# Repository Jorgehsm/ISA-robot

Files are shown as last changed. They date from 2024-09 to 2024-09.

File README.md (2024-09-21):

# ISA robot
Carro robô baseado em esp32 controlado por controle bluetooth.

O projeto utiliza Bluepad32 na comunicação entre o controle e o esp32. Para mais informações acesse: <https://bluepad32.readthedocs.io/en/latest/plat_arduino/>

Desenvolvido utilizando Platform.io.

Breakout board para conexão do esp32 com os diversos sensores e componentes utilizados desenvolvida utilizando KiCad.

imagem

Modelagem do chassi para fabricação em impressão 3D desenvolvida utilizando SolidWorks.

Sem título

Projeto pessoal em desenvolvimento.

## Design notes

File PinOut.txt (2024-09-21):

IR FRENTE - 2
ULTRASSOM - 	TRIG 19
		ECHO 23
ACCEL -	SDA 21
	SCL 22

IR ESQ - 34
IR DIR - 35
BUZZER - 13
BOTAO - 4
LED
LED

MOTORES
ENA 14
IN1 27
IN2 26
IN3 25
IN4 33
ENB 32

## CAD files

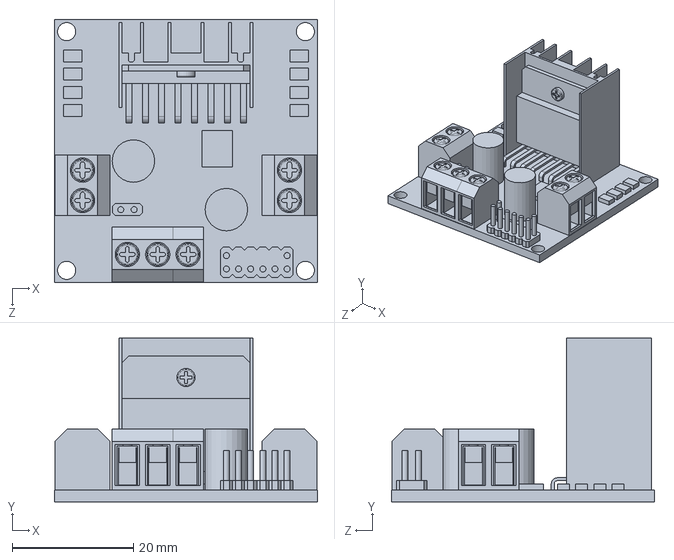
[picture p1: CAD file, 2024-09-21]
CAD/L298N.SLDPRT
43.3 x 27.0 x 43.3 mm

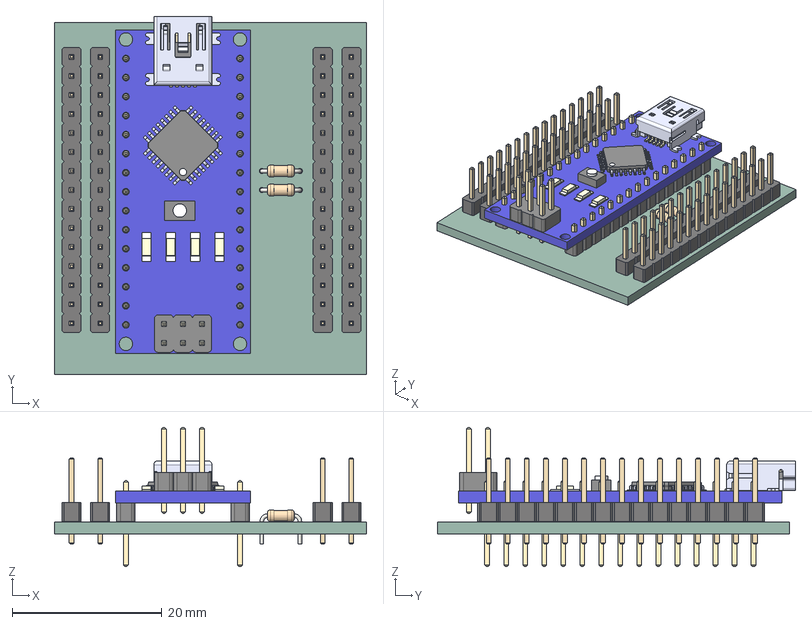
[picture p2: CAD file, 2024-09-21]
pcb_robo_isa_esp/pcb_robo_isa.step
41.7 x 47.8 x 18.6 mm
PinHeader_1x15_P254mm_Vertical x 4
ARDUINO NANO 3.0
R_Axial_DIN0204_L36mm_D16mm_P508mm_Horizontal x 2
_autosave-pcb_robo_isa_PCB

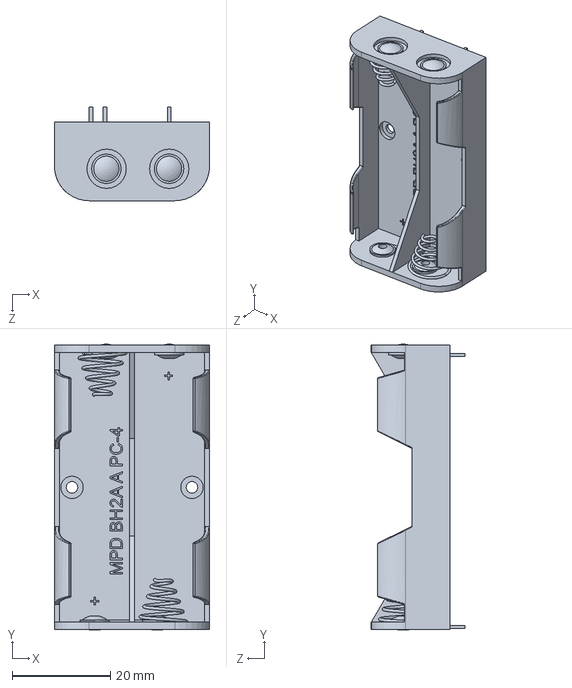
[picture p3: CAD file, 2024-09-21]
CAD/AABattery Holder.SLDPRT
31.5 x 58.1 x 19.0 mm

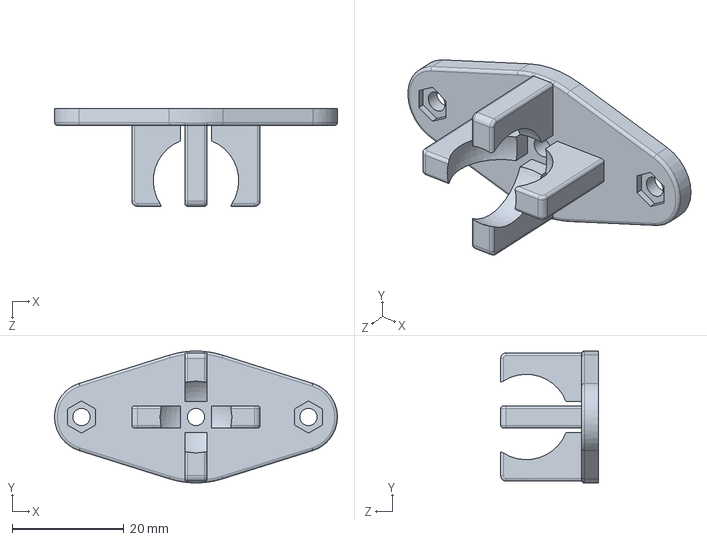
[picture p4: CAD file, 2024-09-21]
CAD/roda_boba.SLDPRT
50.7 x 23.6 x 17.5 mm

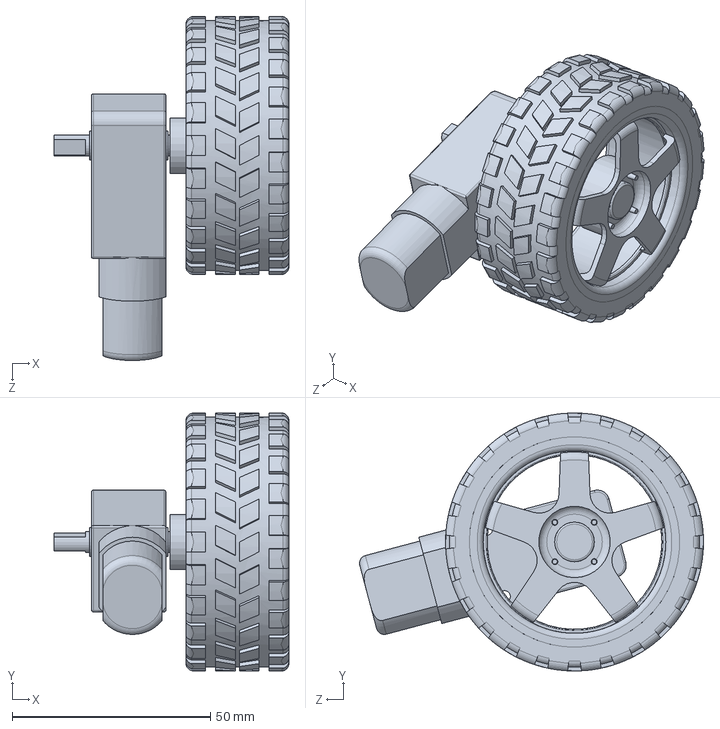
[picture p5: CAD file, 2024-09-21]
CAD/dc_motor_and_wheel.SLDPRT
59.2 x 65.0 x 86.7 mm

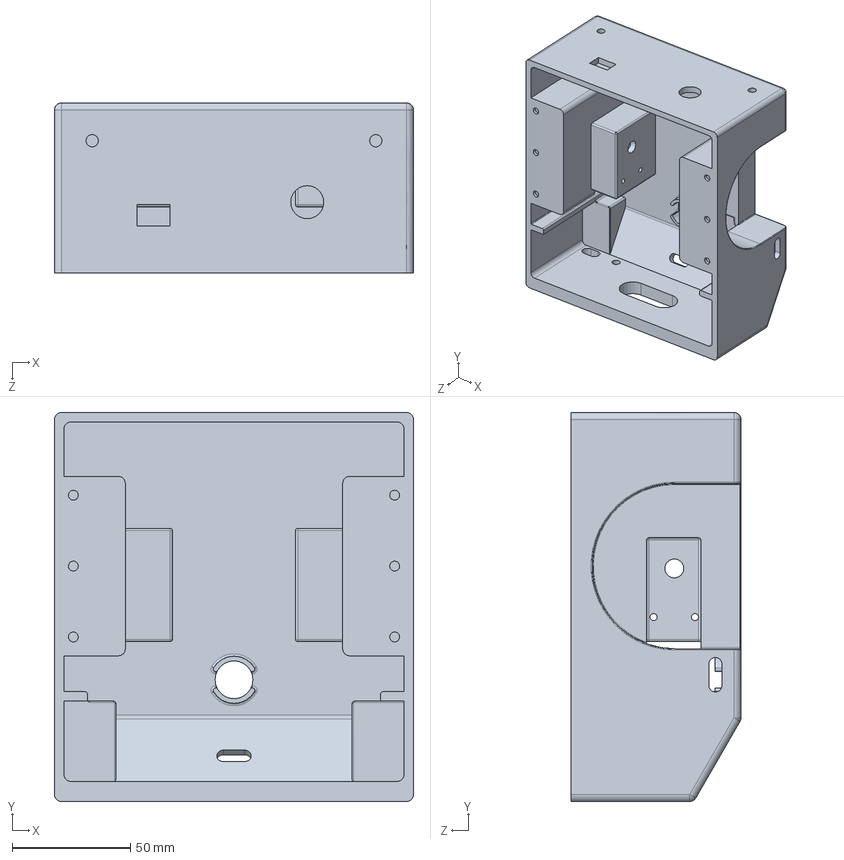
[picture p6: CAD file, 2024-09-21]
CAD/chassi.SLDPRT
152.0 x 164.6 x 72.0 mm

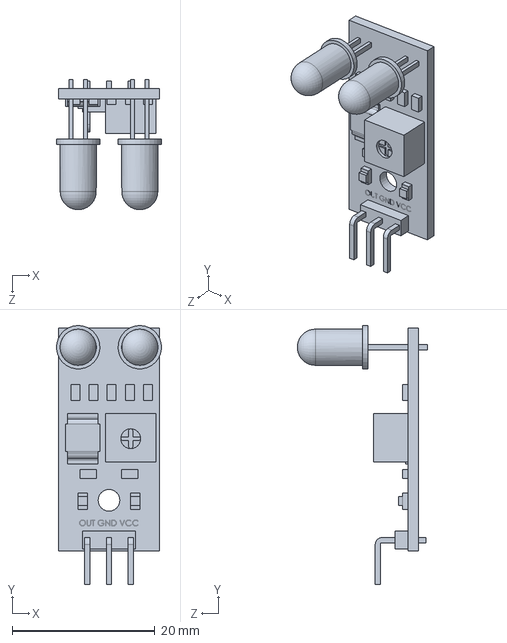
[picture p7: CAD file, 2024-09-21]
CAD/IR Sensor (FC51).SLDPRT
14.7 x 36.3 x 18.3 mm

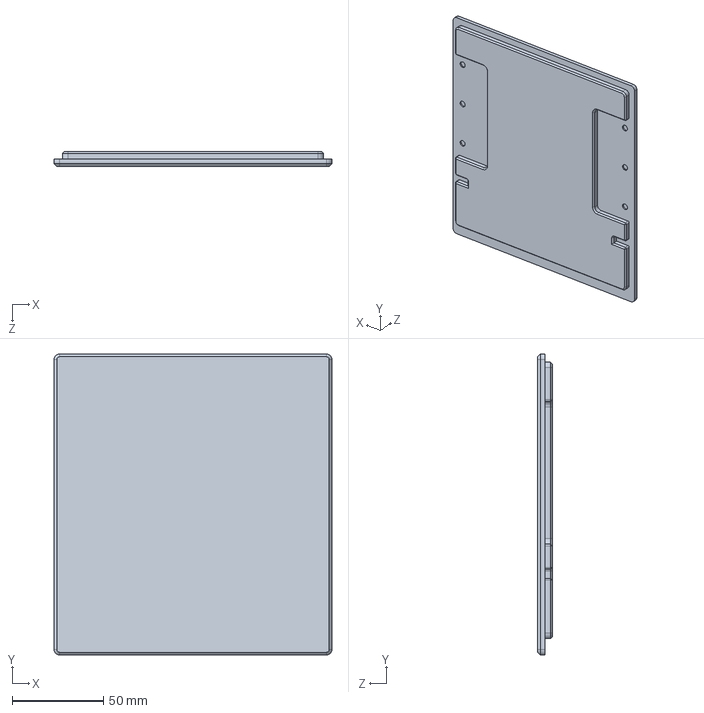
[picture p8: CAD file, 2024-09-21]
CAD/tampa.SLDPRT
152.0 x 164.6 x 8.00 mm

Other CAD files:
CAD/pcb_robo_isa.SLDPRT
CAD/chassi_rodamaior.SLDPRT

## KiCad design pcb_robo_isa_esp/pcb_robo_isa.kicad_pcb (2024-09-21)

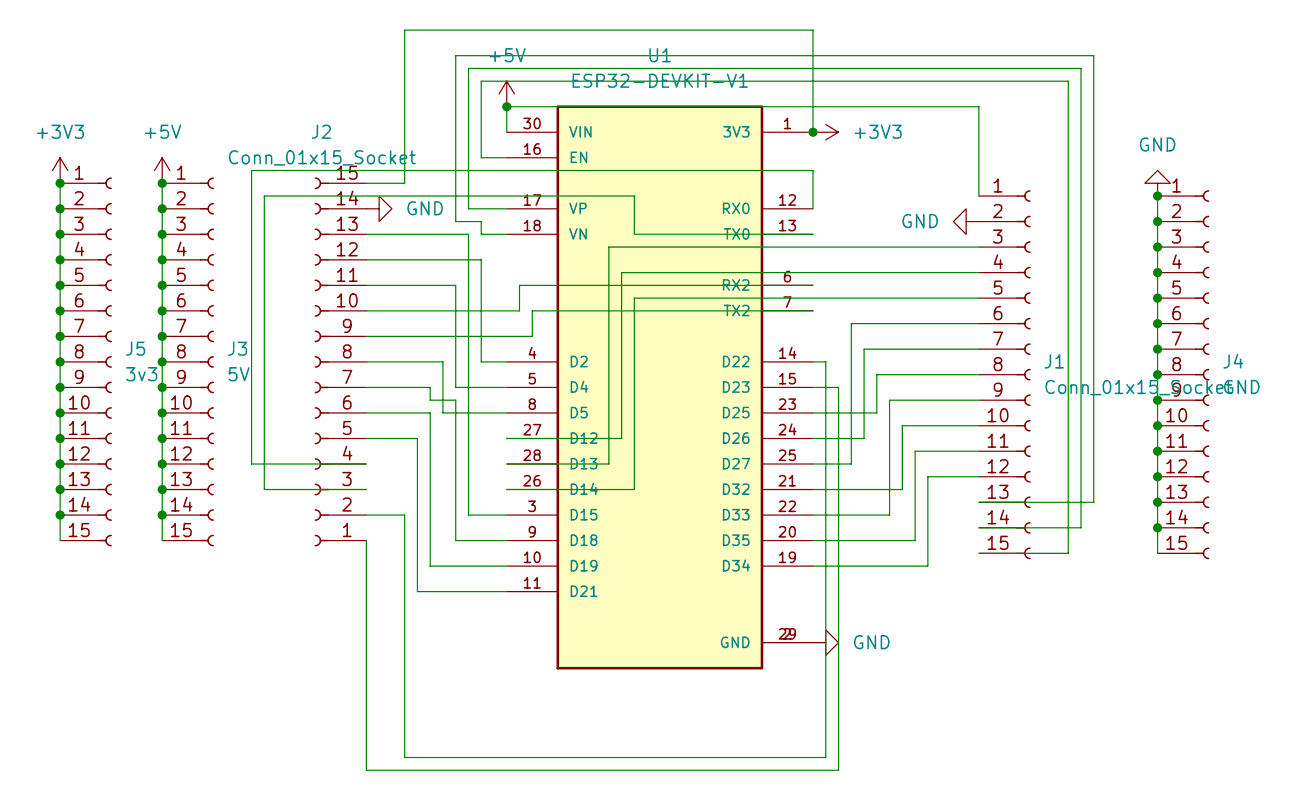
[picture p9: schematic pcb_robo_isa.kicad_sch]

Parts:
J1, J2: Conn_01x15_Socket; PinHeader_1x15_P2.54mm_Vertical
J3: 5V; PinHeader_1x15_P2.54mm_Vertical
J4: GND; PinHeader_1x15_P2.54mm_Vertical
J5: 3v3; PinHeader_1x15_P2.54mm_Vertical
U1: ESP32-DEVKIT-V1; MODULE_ESP32_DEVKIT_V1; PARTREV N/A

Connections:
+3V3: J2.15, J5.1, J5.2, J5.3, J5.4, J5.5, J5.6, J5.7, J5.8, J5.9, J5.10, J5.11, J5.12, J5.13, J5.14, J5.15, U1.1 (3V3)
+5V: J1.1, J3.1, J3.2, J3.3, J3.4, J3.5, J3.6, J3.7, J3.8, J3.9, J3.10, J3.11, J3.12, J3.13, J3.14, J3.15, U1.30 (VIN)
GND: J1.2, J2.14, J4.1, J4.2, J4.3, J4.4, J4.5, J4.6, J4.7, J4.8, J4.9, J4.10, J4.11, J4.12, J4.13, J4.14, J4.15, U1.2 (GND), U1.29 (GND)
unnamed: J1.3, U1.28 (D13)
unnamed: J1.4, U1.27 (D12)
unnamed: J1.5, U1.26 (D14)
unnamed: J1.6, U1.25 (D27)
unnamed: J1.7, U1.24 (D26)
unnamed: J1.8, U1.23 (D25)
unnamed: J1.9, U1.22 (D33)
unnamed: J1.10, U1.21 (D32)
unnamed: J1.11, U1.20 (D35)
unnamed: J1.12, U1.19 (D34)
unnamed: J1.13, U1.18 (VN)
unnamed: J1.14, U1.17 (VP)
unnamed: J1.15, U1.16 (EN)
unnamed: J2.1, U1.15 (D23)
unnamed: J2.2, U1.14 (D22)
unnamed: J2.3, U1.13 (TX0)
unnamed: J2.4, U1.12 (RX0)
unnamed: J2.5, U1.11 (D21)
unnamed: J2.6, U1.10 (D19)
unnamed: J2.7, U1.9 (D18)
unnamed: J2.8, U1.8 (D5)
unnamed: J2.9, U1.7 (TX2)
unnamed: J2.10, U1.6 (RX2)
unnamed: J2.11, U1.5 (D4)
unnamed: J2.12, U1.4 (D2)
unnamed: J2.13, U1.3 (D15)

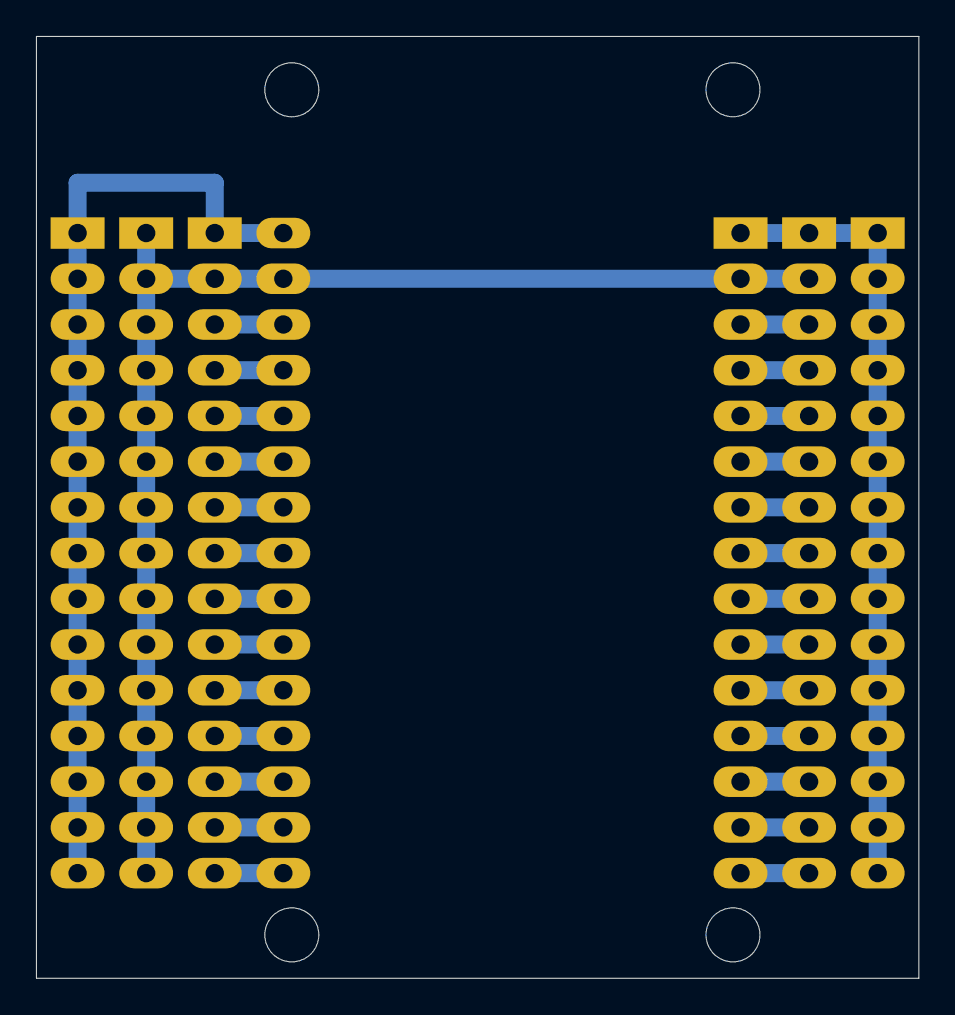
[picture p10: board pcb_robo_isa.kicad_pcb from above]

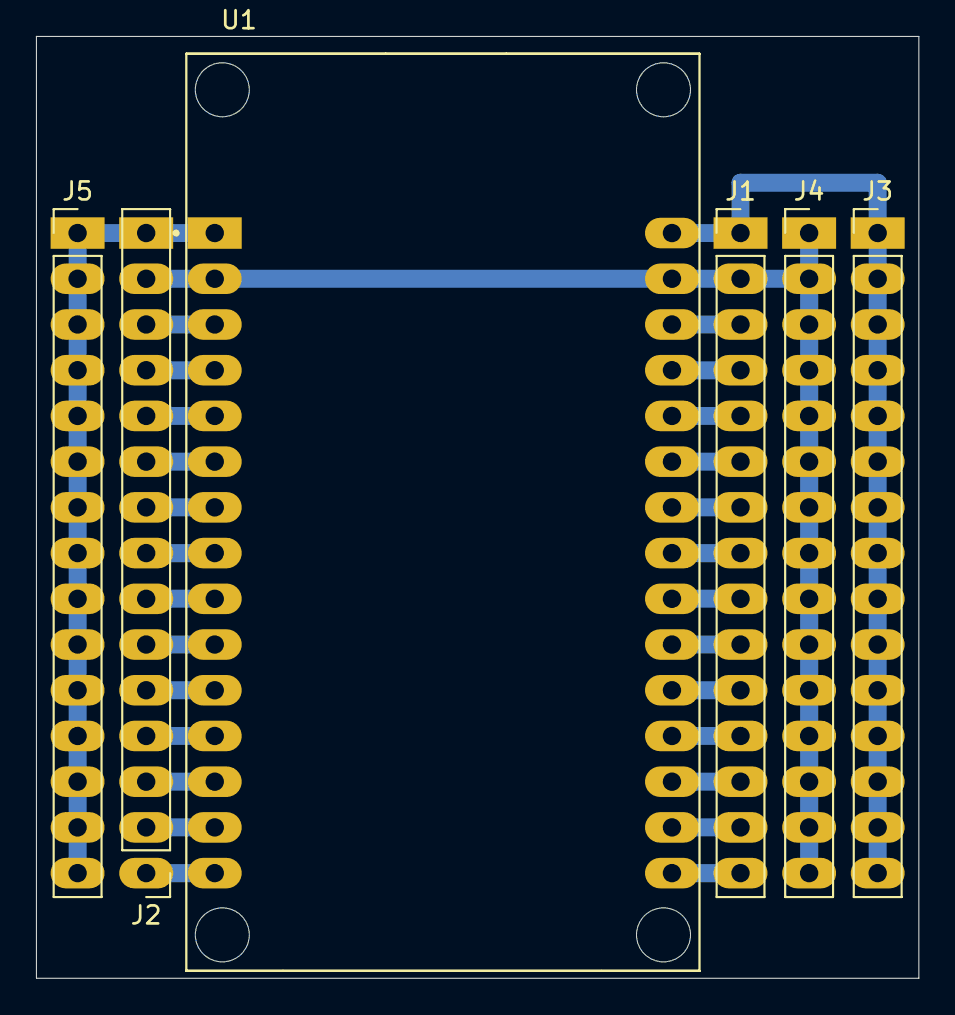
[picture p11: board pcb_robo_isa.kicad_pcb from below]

Board: 2 copper layers, 49.0 x 52.3 mm, 6 parts (6 on the bottom side), 29 nets.

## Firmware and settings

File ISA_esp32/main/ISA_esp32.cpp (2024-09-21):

#include "sdkconfig.h"
#include <Arduino.h>
#include <Bluepad32.h>

int vel = 100, modo = 0;
float turn = 1, Kp = 10, Ki = 1, err = 0, err_ant = 0, err_int = 0;
bool once = 0;
char command = 'A';
unsigned long int tempo = millis();

//*************************************************************************

//ultrassom
#define trigger 19
#define echo 23

float ultrassonico() {
  digitalWrite(trigger, HIGH);
  delayMicroseconds(10);
  digitalWrite(trigger, LOW);
  long tempo = pulseIn(echo, HIGH);
  float distancia = tempo * 0.01715;
  return distancia;
}

//*************************************************************************

//IR direita
#define IRD 34

//IR esquerda
#define IRE 35

//IR anti-queda
#define IRB 2

//************************************************************************

//motor A
#define MA1 27
#define MA2 26
//motor B
#define MB1 25
#define MB2 33

//PWM
#define ENA 14
#define ENB 32

#define M 4

int gas = 0;

//*************************************************************************

#define SPEAKER 13

void MOTOR(int vel, float turn) {
  if (vel > 0 && digitalRead(IRB) == LOW) {
    vel = 255*vel/1020;
    if (turn < 0) {
      digitalWrite(MA1, LOW);
      digitalWrite(MA2, HIGH);
      digitalWrite(MB1, LOW);
      digitalWrite(MB2, HIGH);
      analogWrite(ENA, vel * (turn + 512)/512);
      analogWrite(ENB, vel);
    }

    else if (turn > 0) {
      digitalWrite(MA1, LOW);
      digitalWrite(MA2, HIGH);
      digitalWrite(MB1, LOW);
      digitalWrite(MB2, HIGH);
      analogWrite(ENA, vel);
      analogWrite(ENB, vel * (turn - 508)/-508);
    }

    else if (turn == 0) {
      digitalWrite(MA1, LOW);
      digitalWrite(MA2, HIGH);
      digitalWrite(MB1, LOW);
      digitalWrite(MB2, HIGH);
      analogWrite(ENA, vel);
      analogWrite(ENB, vel);
    }
  }

  else if (vel < 0) {
    digitalWrite(MA1, HIGH);
    digitalWrite(MA2, LOW);
    digitalWrite(MB1, HIGH);
    digitalWrite(MB2, LOW);
    analogWrite(ENA, -vel);
    analogWrite(ENB, -vel);
  }

}

void VIRAR(int vel) {
  vel = map(vel, -100, 100, -255, 255);
  //direita > 0
  if (vel > 0) {
    digitalWrite(MA1, LOW);
    digitalWrite(MA2, HIGH);
    digitalWrite(MB1, HIGH);
    digitalWrite(MB2, LOW);
    analogWrite(ENA, vel);
    analogWrite(ENB, vel);

    //esquerda < 0
  } else if (vel < 0) {
    digitalWrite(MA1, HIGH);
    digitalWrite(MA2, LOW);
    digitalWrite(MB1, LOW);
    digitalWrite(MB2, HIGH);
    analogWrite(ENA, -vel);
    analogWrite(ENB, -vel);
  }
}

void BREAK() {
  digitalWrite(MA1, LOW);
  digitalWrite(MA2, LOW);
  digitalWrite(MB1, LOW);
  digitalWrite(MB2, LOW);
}

ControllerPtr myControllers[BP32_MAX_GAMEPADS];

void onConnectedController(ControllerPtr ctl) {
    bool foundEmptySlot = false;
    for (int i = 0; i < BP32_MAX_GAMEPADS; i++) {
        if (myControllers[i] == nullptr) {
            Console.printf("CALLBACK: Controller is connected, index=%d\n", i);
            ControllerProperties properties = ctl->getProperties();
            Console.printf("Controller model: %s, VID=0x%04x, PID=0x%04x\n", ctl->getModelName(), properties.vendor_id,
                           properties.product_id);
            myControllers[i] = ctl;
            foundEmptySlot = true;
            break;
        }
    }
    if (!foundEmptySlot) {
        Console.println("CALLBACK: Controller connected, but could not found empty slot");
    }
}

void onDisconnectedController(ControllerPtr ctl) {
    bool foundController = false;

    for (int i = 0; i < BP32_MAX_GAMEPADS; i++) {
        if (myControllers[i] == ctl) {
            Console.printf("CALLBACK: Controller disconnected from index=%d\n", i);
            myControllers[i] = nullptr;
            foundController = true;
            break;
        }
    }

    if (!foundController) {
        Console.println("CALLBACK: Controller disconnected, but not found in myControllers");
    }
}

void dumpGamepad(ControllerPtr ctl) {
    Console.printf(
        "idx=%d, dpad: 0x%02x, buttons: 0x%04x, axis L: %4d, %4d, axis R: %4d, %4d, brake: %4d, throttle: %4d, misc: 0x%02x\n",
        ctl->index(),        // Controller Index
        ctl->dpad(),         // D-pad
        ctl->buttons(),      // bitmask of pressed buttons
        ctl->axisX(),        // (-511 - 512) left X Axis
        ctl->axisY(),        // (-511 - 512) left Y axis
        ctl->axisRX(),       // (-511 - 512) right X axis
        ctl->axisRY(),       // (-511 - 512) right Y axis
        ctl->brake(),        // (0 - 1023): brake button
        ctl->throttle(),     // (0 - 1023): throttle (AKA gas) button
        ctl->miscButtons()  // bitmask of pressed "misc" buttons
    );
}

void processGamepad(ControllerPtr ctl) {
    if(ctl->throttle() > 200){
        gas = ctl->throttle();
    }

    if(ctl->brake() > 200){
        gas = -ctl->brake();
    }

    if(ctl->x()) {
      digitalWrite(SPEAKER, HIGH);
    }

    if(!ctl->x()) {
      digitalWrite(SPEAKER, LOW);
    }
    else if(ctl->brake() < 200 && ctl->throttle() < 200){
        gas = 0;
        turn = 0;
        BREAK();
    }

    turn = ctl->axisX();
    MOTOR(gas, turn);
    dumpGamepad(ctl);
}

void processControllers() {
    for (auto myController : myControllers) {
        if (myController && myController->isConnected() && myController->hasData()) {
            if (myController->isGamepad()) {
                processGamepad(myController);
            } else {
                Console.printf("Unsupported controller\n");
            }
        }
    }
}

void setup() {
  //IR controle de dedo
  pinMode(IRD, INPUT);
  pinMode(IRE, INPUT);
  pinMode(IRB, INPUT);

  //setup motor
  pinMode(MA1, OUTPUT);
  pinMode(MA2, OUTPUT);
  pinMode(MB1, OUTPUT);
  pinMode(MB2, OUTPUT);
  pinMode(ENA, OUTPUT);
  pinMode(ENB, OUTPUT);

  //ultrassom setup
  pinMode(trigger, OUTPUT);
  pinMode(echo, INPUT);

  //setup mudanca de modo
  pinMode(M, INPUT_PULLDOWN);
  pinMode(SPEAKER, OUTPUT);


    Console.printf("Firmware: %s\n", BP32.firmwareVersion());
    const uint8_t* addr = BP32.localBdAddress();
    Console.printf("BD Addr: %2X:%2X:%2X:%2X:%2X:%2X\n", addr[0], addr[1], addr[2], addr[3], addr[4], addr[5]);
    BP32.setup(&onConnectedController, &onDisconnectedController);
    BP32.forgetBluetoothKeys();
    BP32.enableVirtualDevice(false);
    BP32.enableBLEService(false);
}

void loop() {
bool dataUpdated = BP32.update();
    if (dataUpdated)
        processControllers();

    vTaskDelay(1);
    delay(50);
}

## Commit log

2024-09-21 Adição do modelo 3D e projeto da PCB
    [AABattery Holder.SLDPRT, IR Sensor (FC51).SLDPRT, L298N.SLDPRT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]
2024-09-21 PinOut de conexão dos componentes no esp32
